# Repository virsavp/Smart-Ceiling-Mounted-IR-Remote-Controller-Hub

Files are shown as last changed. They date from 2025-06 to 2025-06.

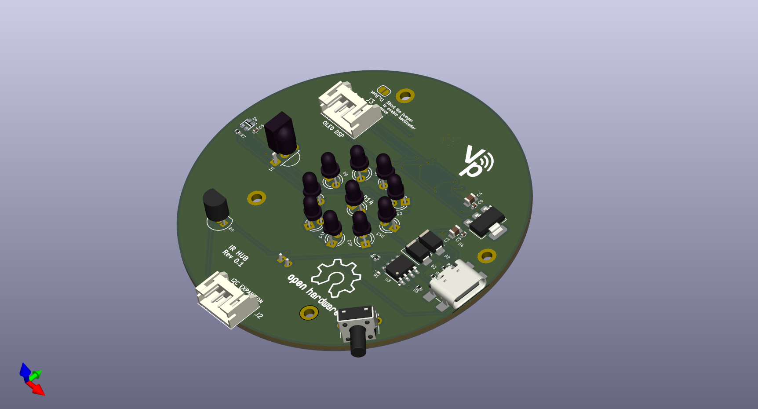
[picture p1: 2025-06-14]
Images/3D ir hub.png

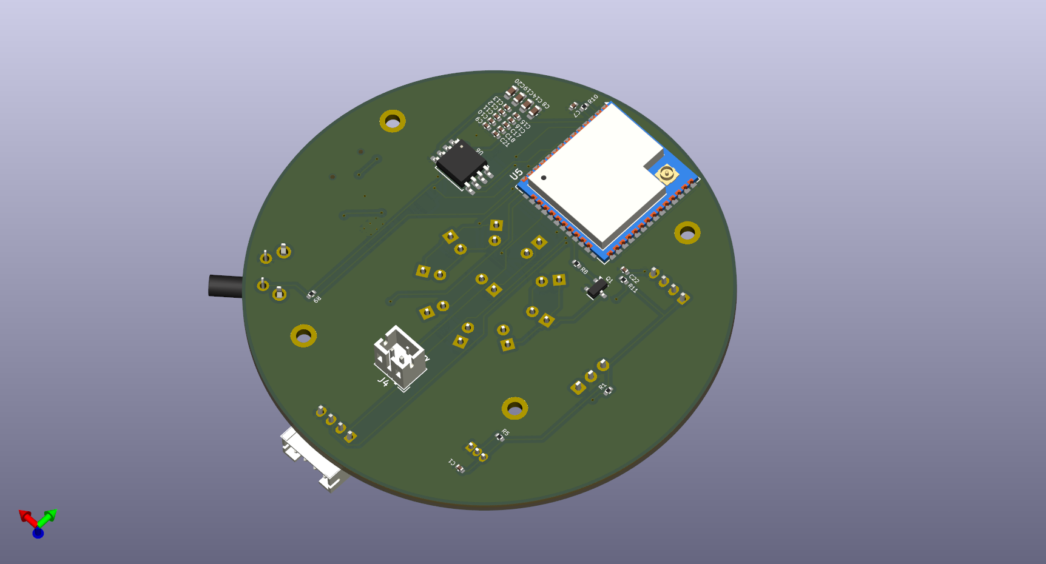
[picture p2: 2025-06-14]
Images/3D ir hub BACK.png

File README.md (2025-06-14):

Universal Remote Controller Hub

📂 Jump to Files:

🔧 Hardware (schematics & PCB)
💻 Firmware Code (coming soon)

This project is a compact, ceiling-mountable, smart IR controller hub based on the ESP32-S3-WROOM. 
It enables universal control of IR-based appliances like TVs, air conditioners, and fans using web UI, OTA, and automation features.

✨ Features

🔁 360° IR transmission with 10× TSAL6200 high-power IR LEDs
🔍 IR learning using TSOP38238 receiver
📡 Wi-Fi OTA updates + USB flashing via BOOT jumper
🌡️ DS18B20 temperature sensor (for fan/AC automation)
🔊 Optional WS2812 RGB LED status indicator
🖥️ Optional OLED display via JST I²C header (GPIO17/18)
🔘 Single config/setup button (GPIO2, safe boot compliant)
💾 External SPI flash (W25Q256JV) for IR code storage
🔌 USB-C power + LiPo battery with TP4056 charge module
🧲 Magnetic ceiling-mount enclosure with transparent IR window and venting

🧱 Hardware Overview	
	
Component	Details
MCU	- ESP32-S3 WROOM
IR TX	- 10× TSAL6200 + 2N2222 transistor driver
IR RX	- TSOP38238
Temp Sensor	- DS18B20 (GPIO10)
OLED Display	- SSD1306 via I²C (GPIO17=SDA, GPIO18=SCL)
RGB LED	- WS2812-2020 (GPIO16)
Button	- Config input on GPIO2 (1k pull-up)
External Flash	- W25Q256JV (CS: GPIO13, CLK: GPIO15, MOSI: GPIO5, MISO: GPIO4)
Power Input	- USB-C + LiPo via TP4056
Regulator	- AMS1117-3.3

📁 Repository Structure

/hardware/         → KiCad schematics, PCB files (licensed under CERN-OHL-S)
/3d_model/         → Enclosure STL or CAD (licensed under CC BY-SA 4.0)
/code/             → ESP32 firmware (to be added after layout)
LICENSE            → Dual license for hardware and enclosure
README.md          → This file

🧾 License

🔧 Schematics & PCB Design: CERN-OHL-S v2

🚧 Development Status

✅ Hardware design complete✅ PCB layout and routing complete🔲 Firmware development starts after placement confirmation

🙌 Contributions

Feel free to fork, improve, or repurpose this design. If you build upon it, keep it open-source under the same licenses.
For issues or suggestions, please open a GitHub issue or contact the maintainer.

Made with ❤️ by Vishnu – Electronics Hobbyist | KiCad Enthusiast | Open Hardware Advocate

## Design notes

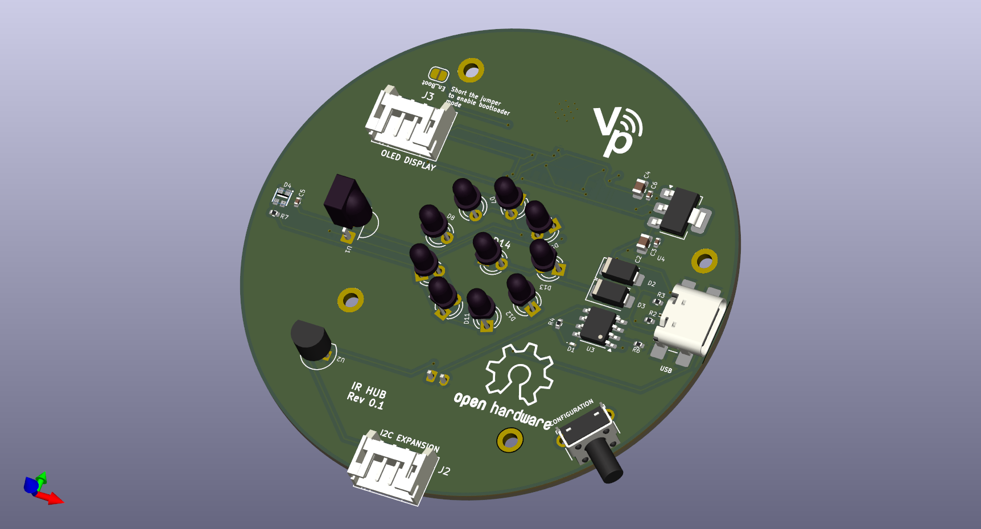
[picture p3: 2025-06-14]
Images/PROJECT.png

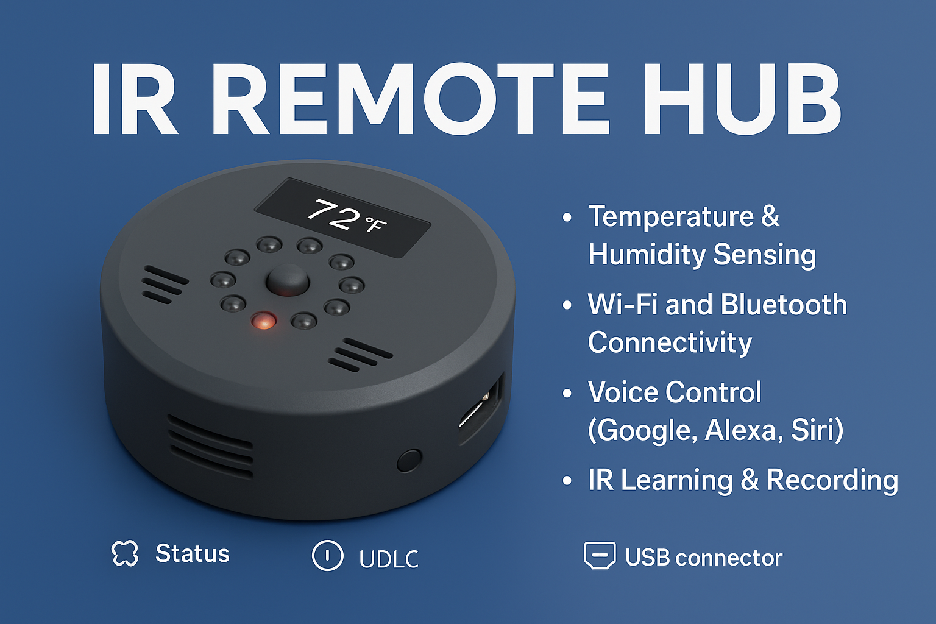
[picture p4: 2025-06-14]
Images/IR Hub.png

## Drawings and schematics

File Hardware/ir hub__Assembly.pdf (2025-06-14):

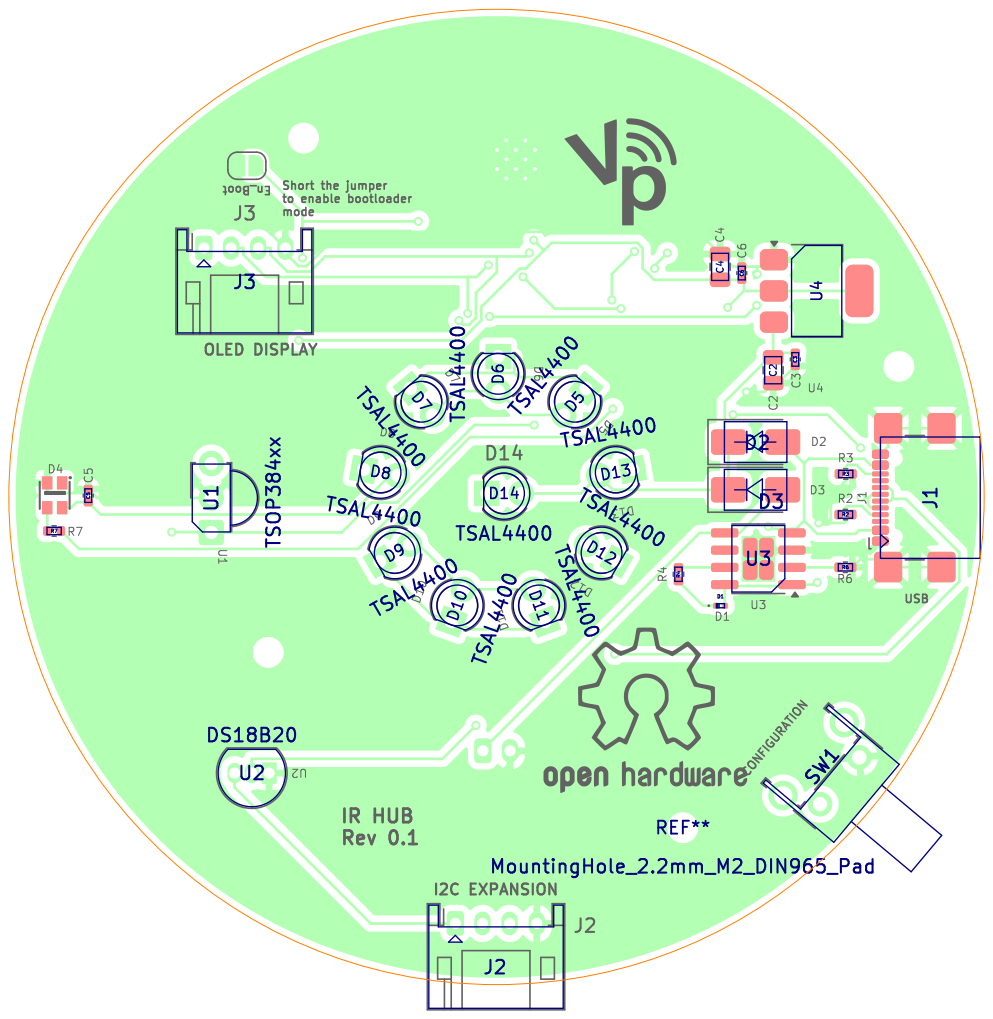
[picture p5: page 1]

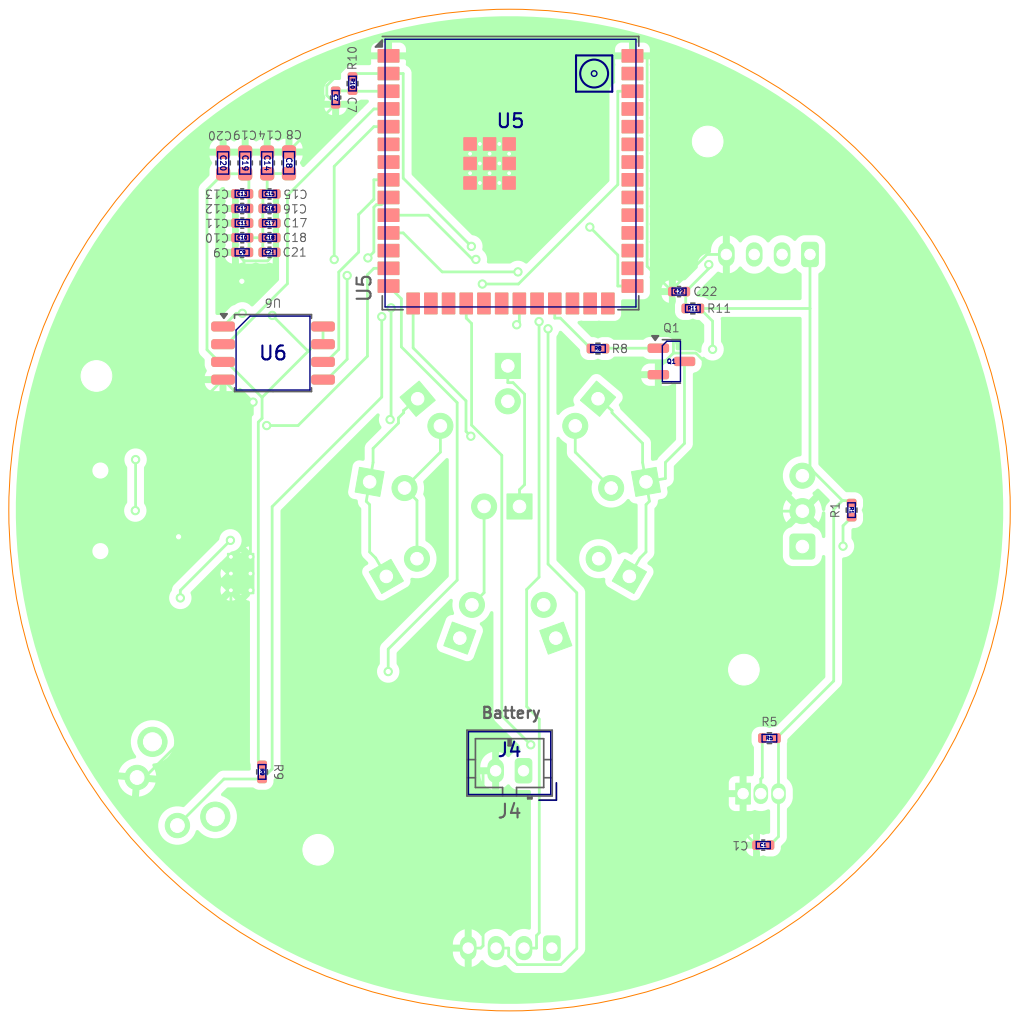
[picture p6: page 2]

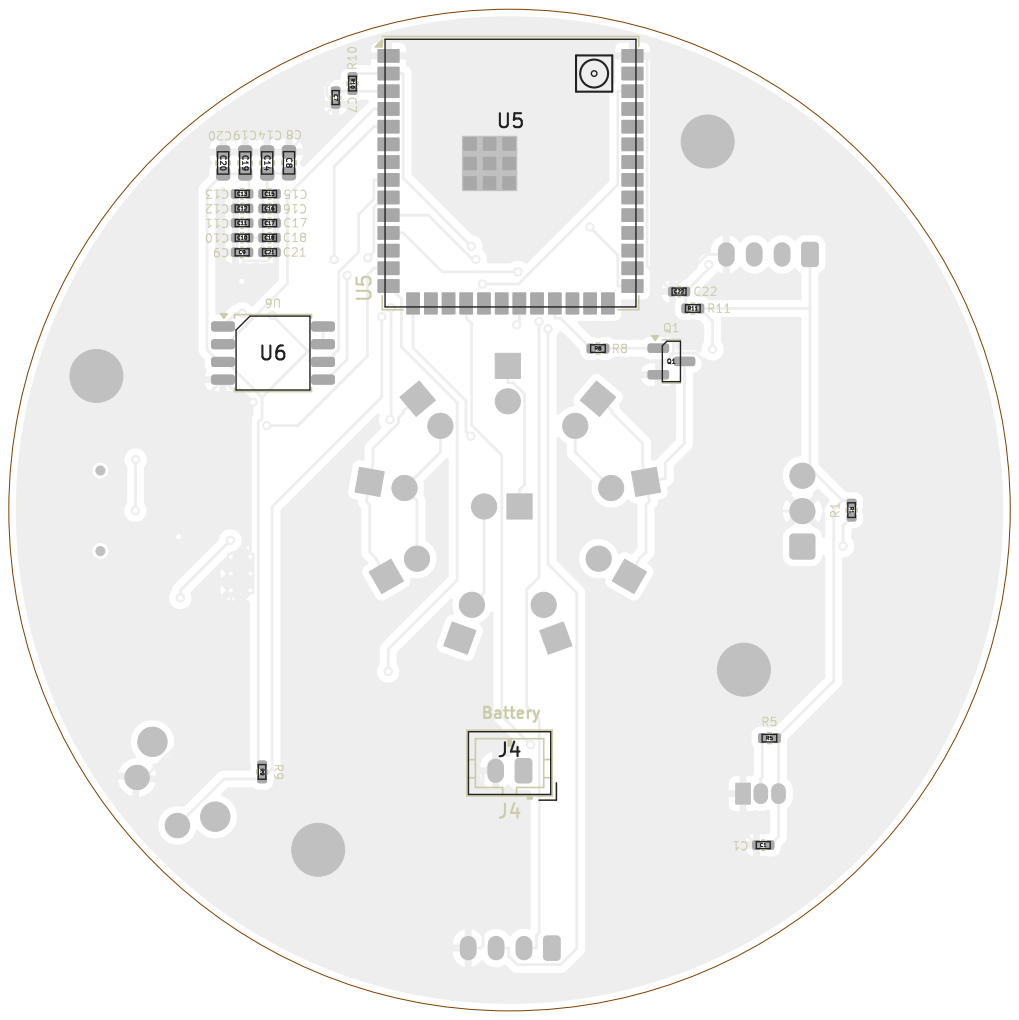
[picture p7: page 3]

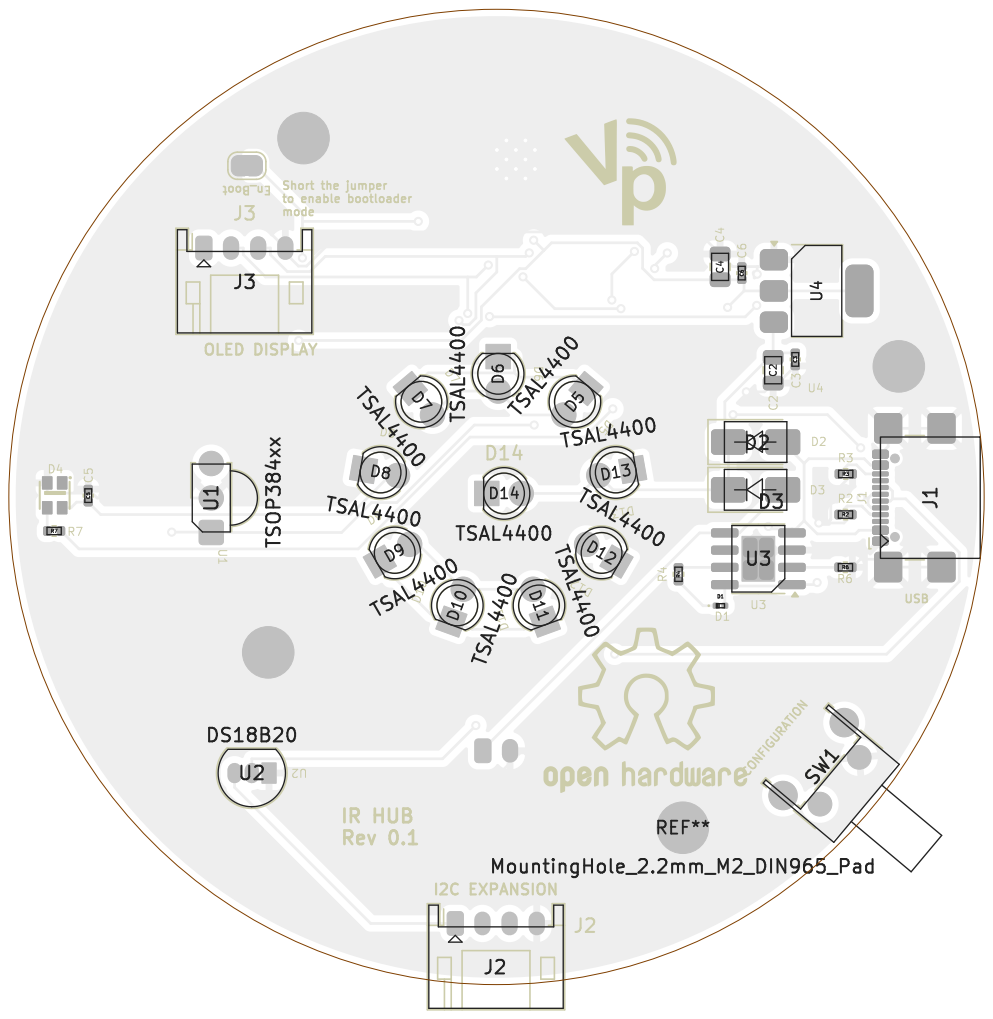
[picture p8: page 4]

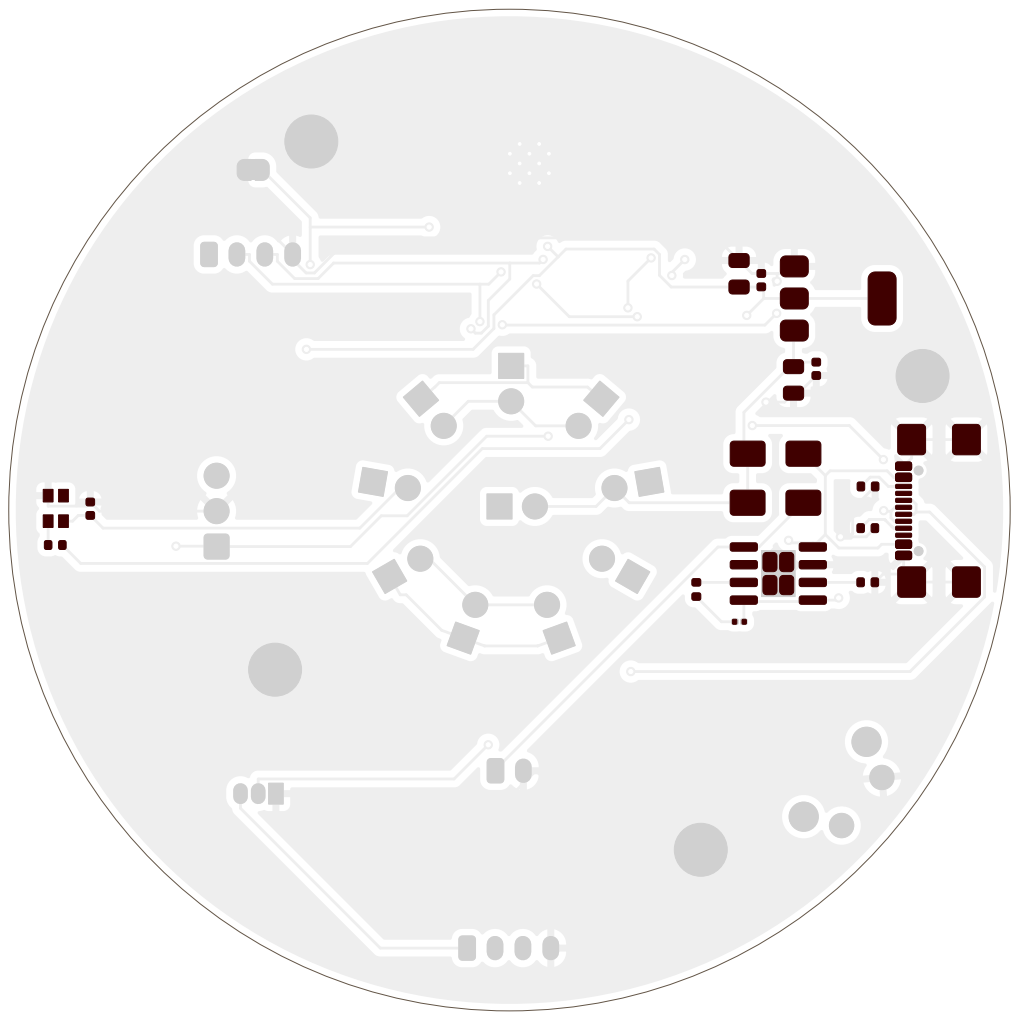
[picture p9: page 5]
D Date: KiCad; E.D.A. 9.0.2 Size: A4; Rev:; Id: /1 Title: File: ir; hub.kicad_pcb Sheet: Light Colors; PCB; Paste; TOP; Board2Pdf:; Light Colors; TOP -; Page 5/6

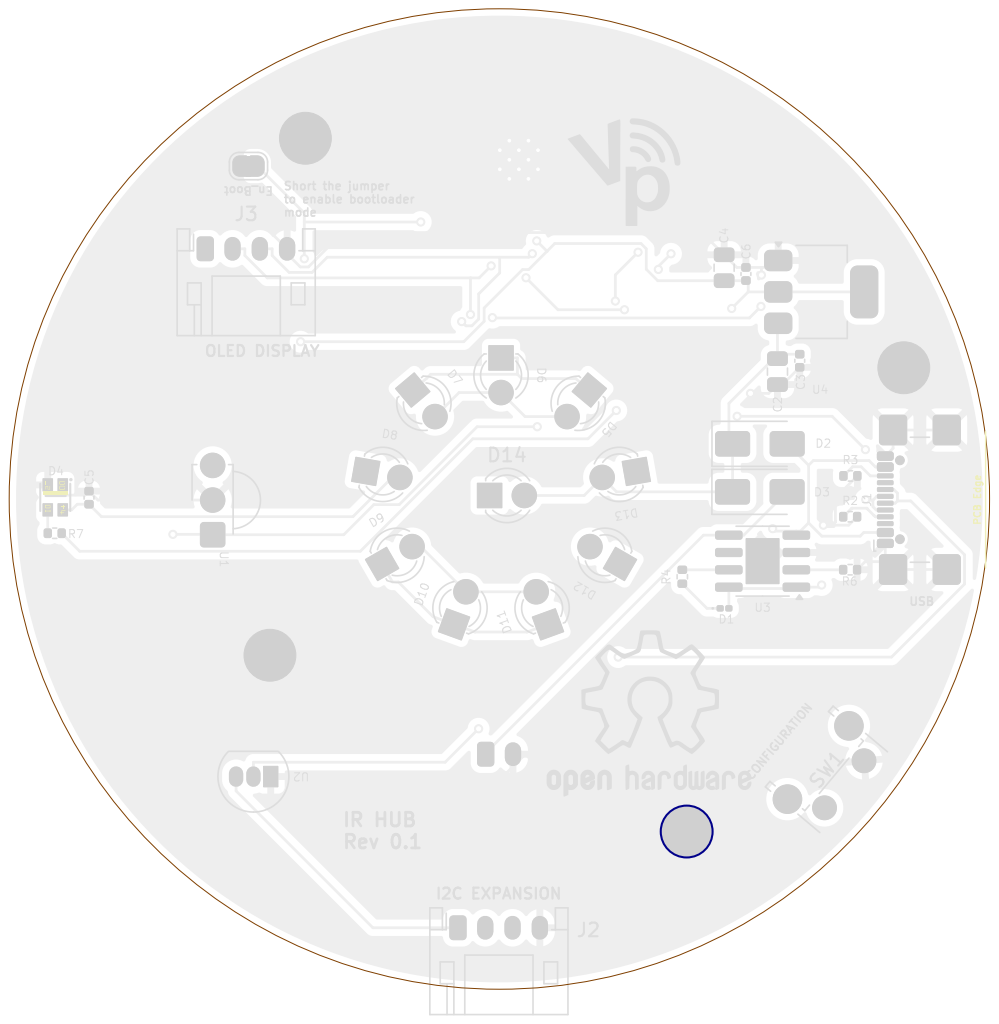
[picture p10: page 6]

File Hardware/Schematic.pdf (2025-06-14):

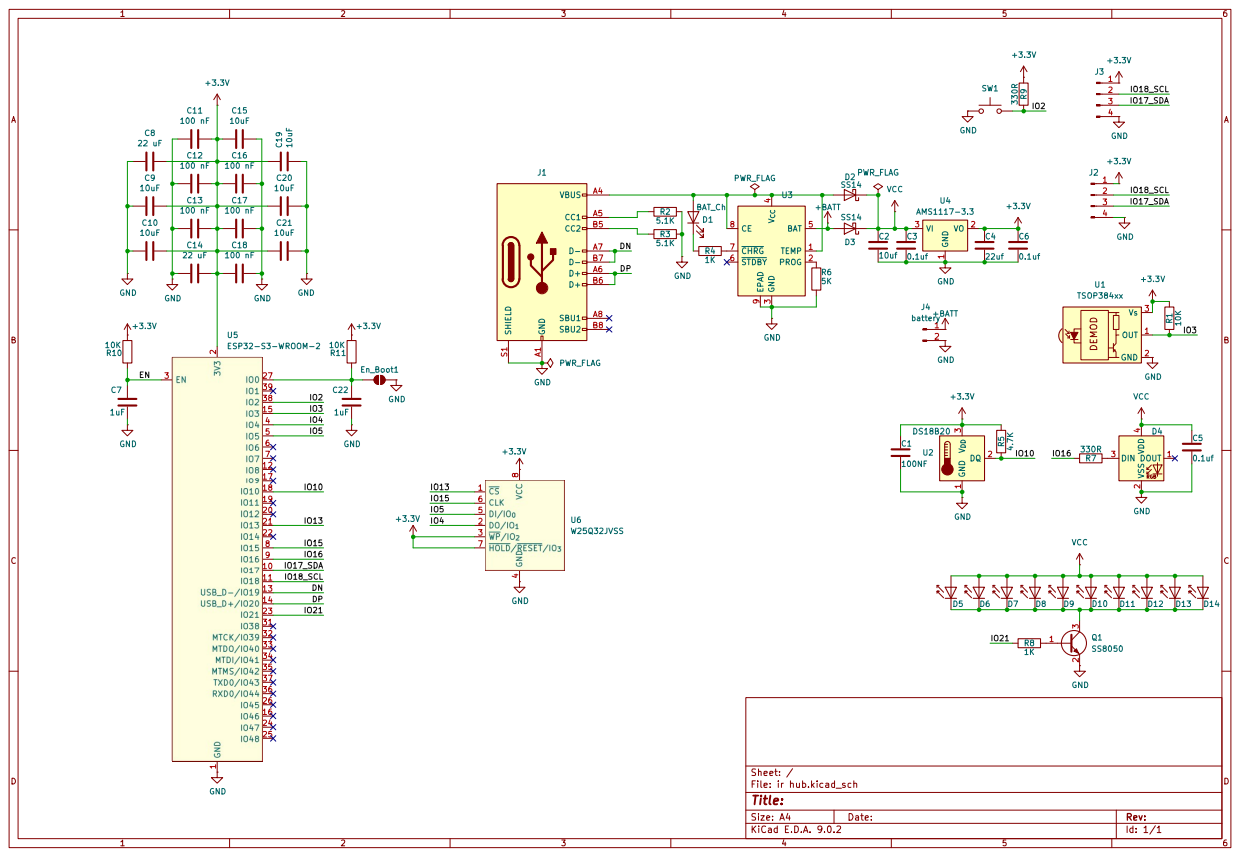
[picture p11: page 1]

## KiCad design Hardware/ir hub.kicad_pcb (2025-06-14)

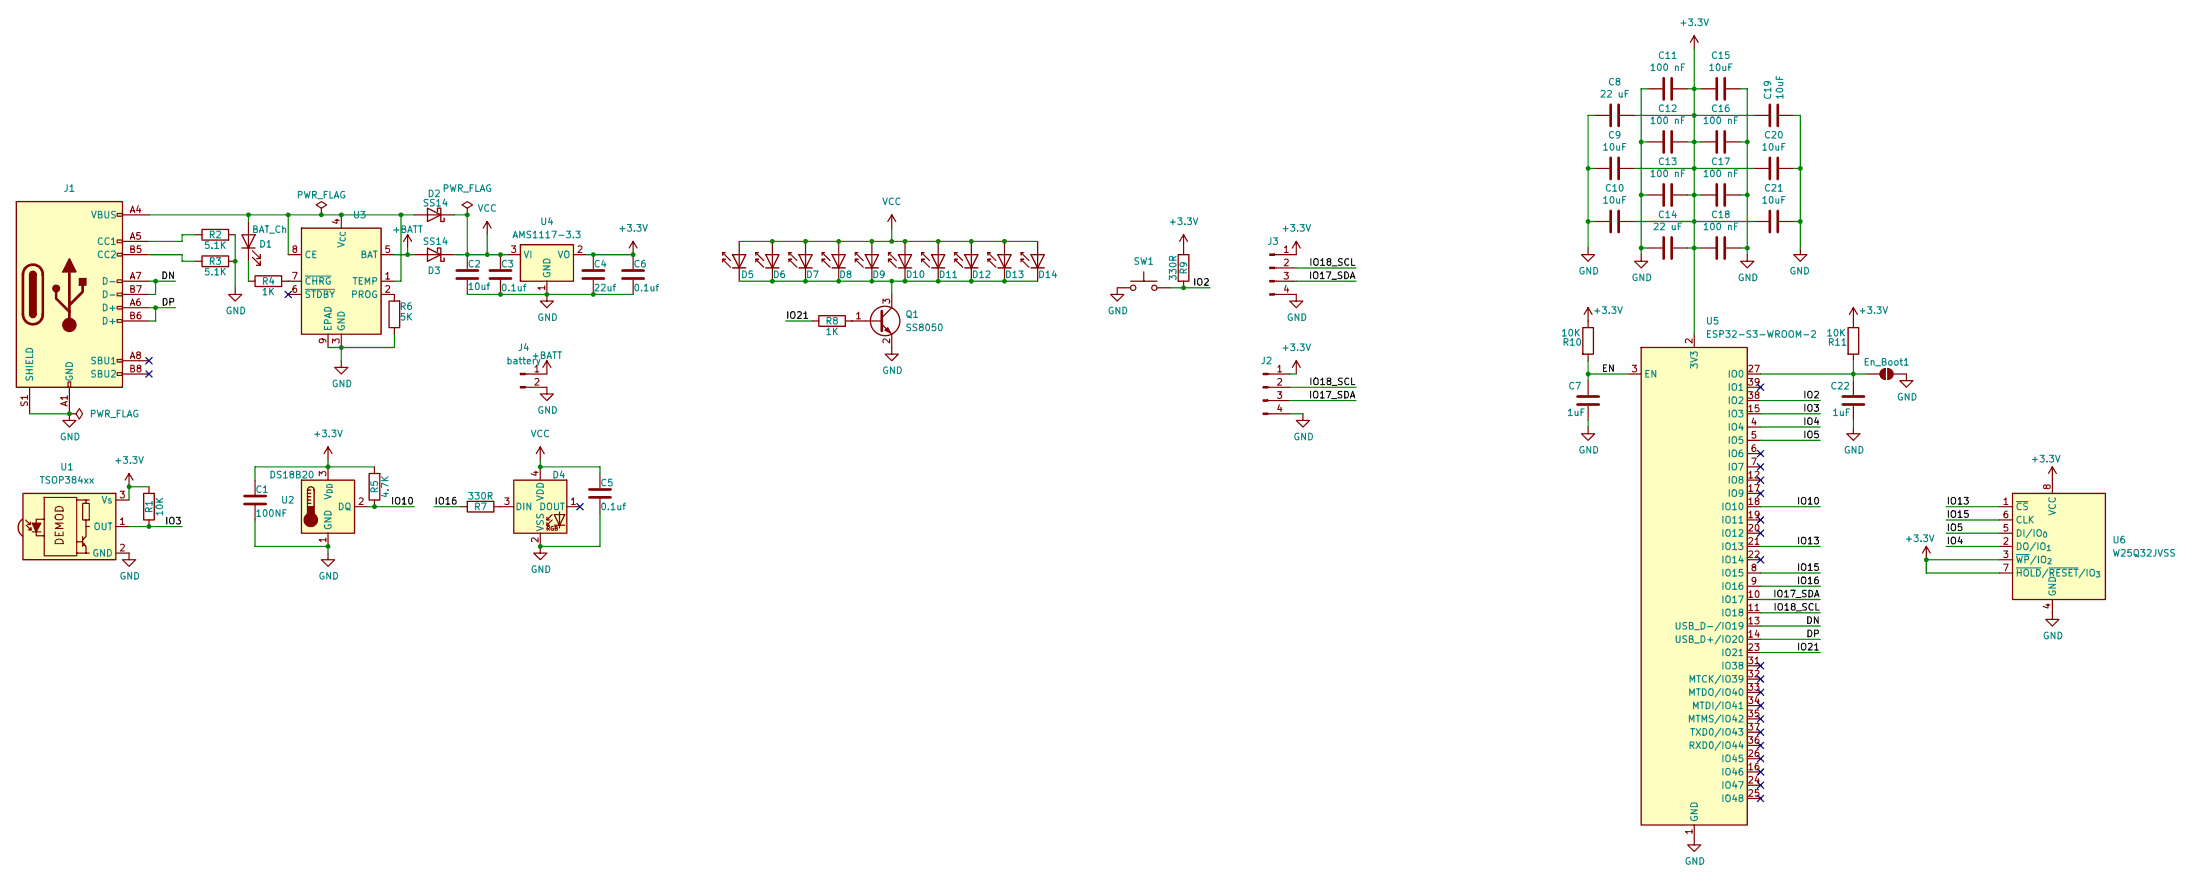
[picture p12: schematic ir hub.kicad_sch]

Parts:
C1: 100NF; C_0402_1005Metric
C2: 10uf; C_0805_2012Metric
C3, C5, C6: 0.1uf; C_0402_1005Metric
C4: 22uf; C_0805_2012Metric
C7, C22: 1uF; C_0402_1005Metric; LCSC C52923
C8, C14: 22 uF; C_0603_1608Metric; LCSC C59461
C9, C10, C15, C21: 10uF; C_0402_1005Metric; LCSC C15525
C11, C12, C13, C16, C17, C18: 100 nF; C_0402_1005Metric; LCSC C1525
C19, C20: 10uF; C_0603_1608Metric; LCSC C19702
D1: BAT_Ch; LED_0201_0603Metric
D2, D3: SS14; D_SMA
D4: WS2812B-2020; LED-SMD_4P-L2.0-W2.0-TL_WS2812B-2020
D5, D6, D7, D8, D9, D10, D11, D12, D13, D14: TSAL4400; LED_D3.0mm_IRBlack
En_Boot1: SolderJumper_2_Open; SolderJumper-2_P1.3mm_Open_RoundedPad1.0x1.5mm
J1: USB_C_Receptacle_USB2.0_16P; USB_C_Receptacle_GCT_USB4110
J2: I2C EXPANSION; JST_PH_S4B-PH-K_1x04_P2.00mm_Horizontal
J3: OLED DSP; JST_PH_S4B-PH-K_1x04_P2.00mm_Horizontal
J4: battery; JST_PH_B2B-PH-K_1x02_P2.00mm_Vertical
Q1: SS8050; SOT-23
R1, R10, R11: 10K; R_0402_1005Metric
R2, R3: 5.1K; R_0402_1005Metric
R4, R8: 1K; R_0402_1005Metric
R5: 4.7K; R_0402_1005Metric
R6: 5K; R_0402_1005Metric
R7, R9: 330R; R_0402_1005Metric
SW1: BTN; SW_Tactile_SPST_Angled_PTS645Vx83-2LFS
U1: TSOP384xx; Vishay_MINICAST-3Pin
U2: DS18B20; TO-92_Inline
U3: TP4056-42-ESOP8; SOIC-8-1EP_3.9x4.9mm_P1.27mm_EP2.41x3.3mm_ThermalVias
U4: AMS1117-3.3; SOT-223-3_TabPin2
U5: ESP32-S3-WROOM-2; ESP32-S3-WROOM-1U
U6: W25Q32JVSS; SOIC-8_5.3x5.3mm_P1.27mm

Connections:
+3.3V: C1.1, C4.1, C6.1, C8.1, C9.1, C10.1, C11.1, C12.1, C13.1, C14.1, C15.2, C16.2, C17.2, C18.2, C19.1, C20.2, C21.2, J2.1, J3.1, R1.2, R5.2, R9.1, R10.1, R11.1, U1.3 (Vs), U2.3 (V_{DD}), U4.2 (VO), U5.2 (3V3), U6.3 (~WP/IO_{2}), U6.7 (~HOLD/~RESET/IO_{3}), U6.8 (VCC)
+BATT: D3.2 (A), J4.1, U3.5 (BAT)
/DN: J1.A7 (D-), J1.B7 (D-), U5.13 (USB_D-/IO19)
/DP: J1.A6 (D+), J1.B6 (D+), U5.14 (USB_D+/IO20)
/EN: C7.1, R10.2, U5.3 (EN)
/IO2: R9.2, SW1.2, U5.38 (IO2)
/IO3: R1.1, U1.1 (OUT), U5.15 (IO3)
/IO4: U5.4 (IO4), U6.2 (DO/IO_{1})
/IO5: U5.5 (IO5), U6.5 (DI/IO_{0})
/IO10: R5.1, U2.2 (DQ), U5.18 (IO10)
/IO13: U5.21 (IO13), U6.1 (~CS)
/IO15: U5.8 (IO15), U6.6 (CLK)
/IO16: R7.2, U5.9 (IO16)
/IO17_SDA: J2.3, J3.3, U5.10 (IO17)
/IO18_SCL: J2.2, J3.2, U5.11 (IO18)
/IO21: R8.1, U5.23 (IO21)
GND: C1.2, C2.2, C3.2, C4.2, C5.2, C6.2, C7.2, C8.2, C9.2, C10.2, C11.2, C12.2, C13.2, C14.2, C15.1, C16.1, C17.1, C18.1, C19.2, C20.1, C21.1, C22.2, D4.2 (VSS), En_Boot1.2 (B), J1.A1 (GND), J1.A12 (GND), J1.B1 (GND), J1.B12 (GND), J1.S1 (SHIELD), J2.4, J3.4, J4.2, Q1.2 (E), R2.2, R3.2, R6.1, SW1.1, U1.2 (GND), U2.1 (GND), U3.3 (GND), U3.9 (EPAD), U4.1 (GND), U5.1 (GND), U5.40 (GND), U5.41 (GND), U6.4 (GND); also elsewhere on the board
unnamed: D1.2 (A), D2.2 (A), J1.A4 (VBUS), J1.A9 (VBUS), J1.B4 (VBUS), J1.B9 (VBUS), U3.1 (TEMP), U3.4 (V_{CC}), U3.8 (CE)
unnamed: D1.1 (K), R4.1
unnamed: D4.3 (DIN), R7.1
unnamed: D5.1 (K), D6.1 (K), D7.1 (K), D8.1 (K), D9.1 (K), D10.1 (K), D11.1 (K), D12.1 (K), D13.1 (K), D14.1 (K), Q1.3 (C)
unnamed 21: C22.1, En_Boot1.1 (A), R11.2, U5.27 (IO0); also elsewhere on the board
unnamed: J1.A5 (CC1), R2.1
unnamed: J1.B5 (CC2), R3.1
unnamed: Q1.1 (B), R8.2
unnamed: R6.2, U3.2 (PROG)
unnamed: R4.2, U3.7 (~CHRG)
VCC: C2.1, C3.1, C5.1, D2.1 (K), D3.1 (K), D4.4 (VDD), D5.2 (A), D6.2 (A), D7.2 (A), D8.2 (A), D9.2 (A), D10.2 (A), D11.2 (A), D12.2 (A), D13.2 (A), D14.2 (A), U4.3 (VI)

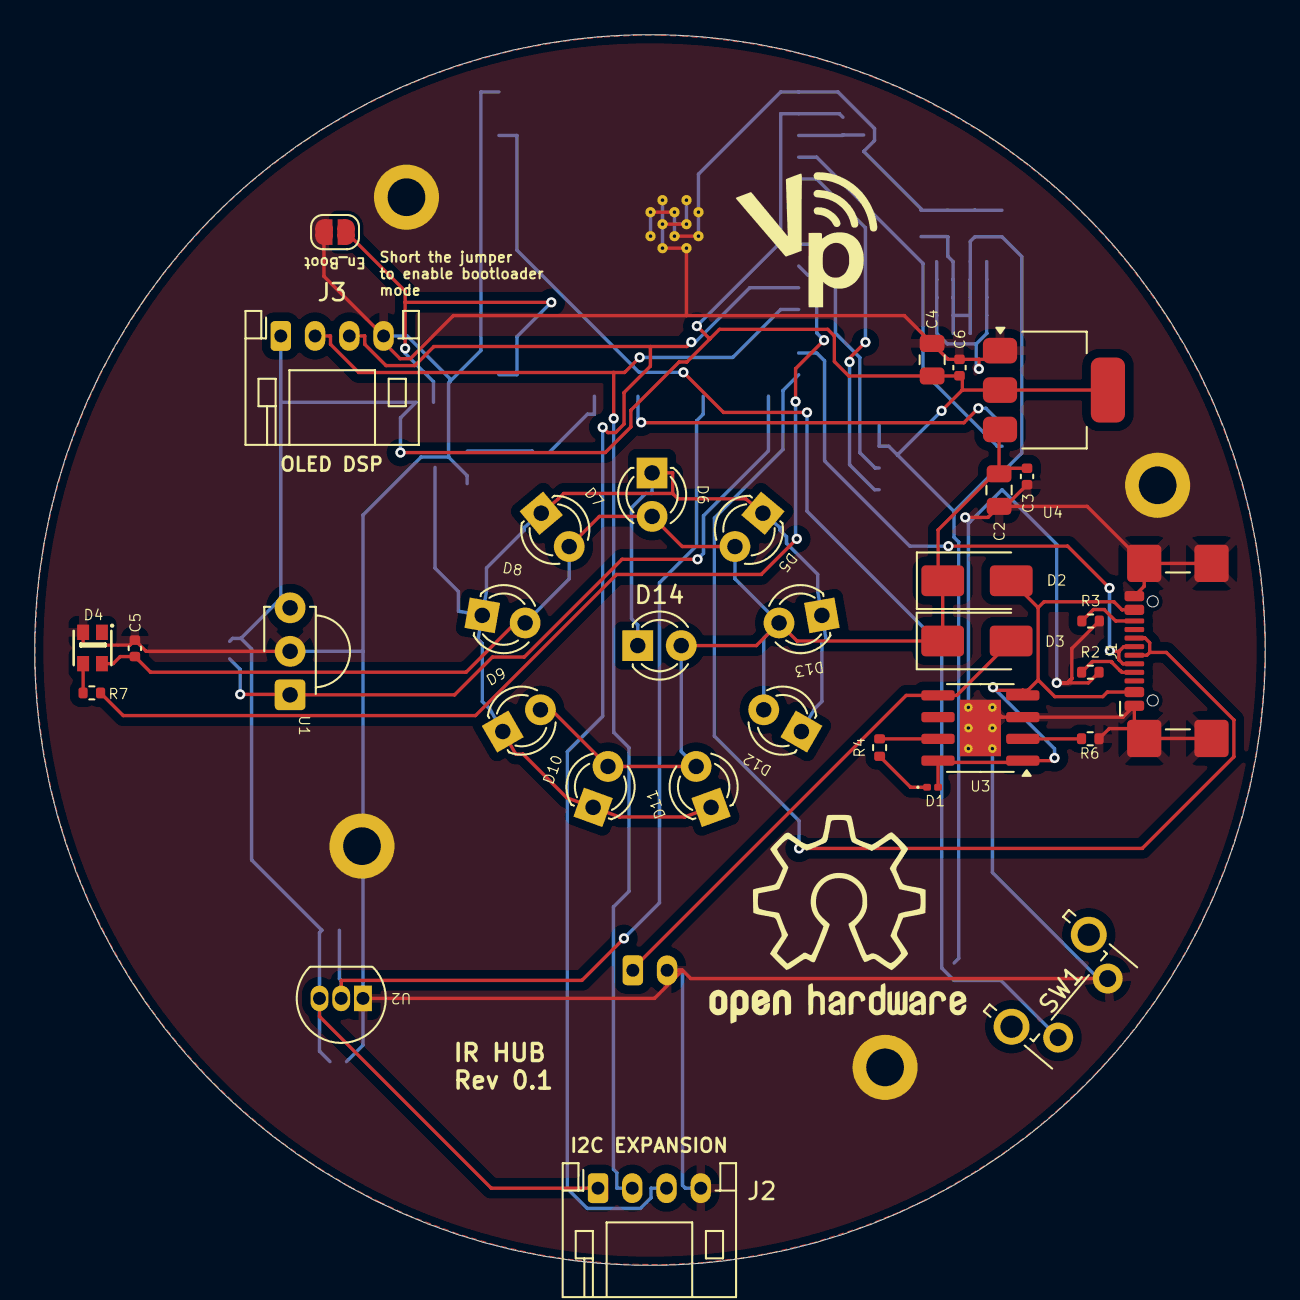
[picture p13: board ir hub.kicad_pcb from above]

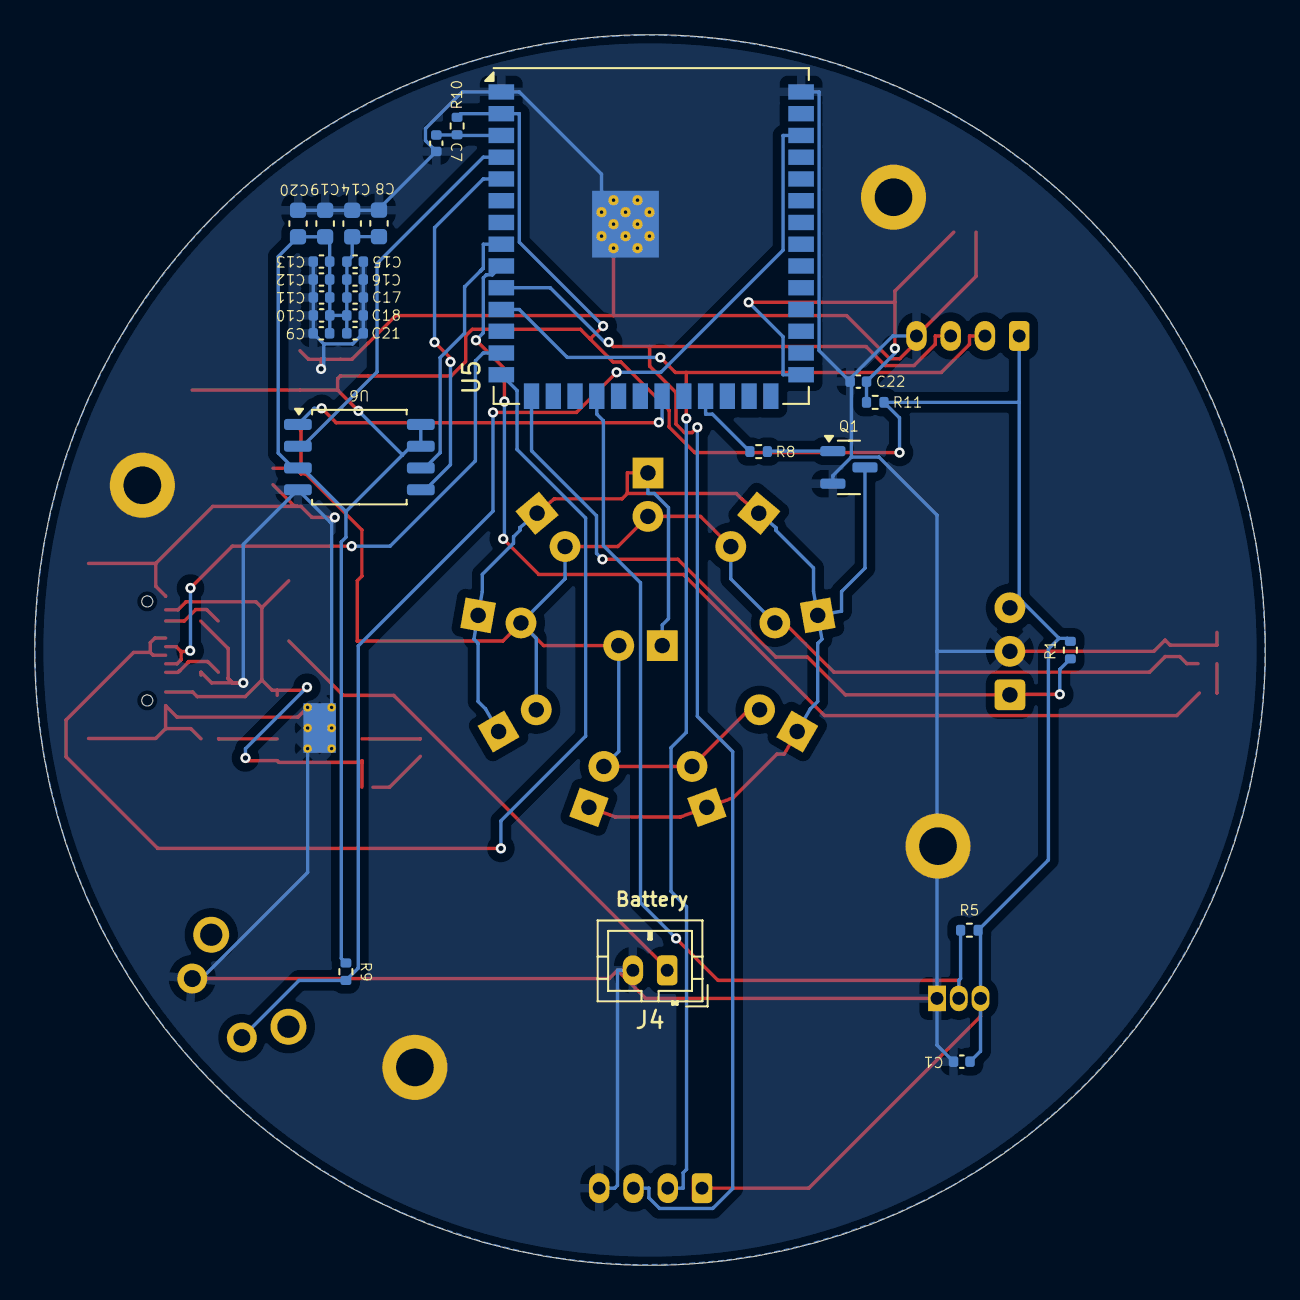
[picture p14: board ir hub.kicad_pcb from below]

Board: 2 copper layers, 71.8 x 71.8 mm, 60 parts (27 on the bottom side), 28 nets.

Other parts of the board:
En_Boot: SolderJumper_2_Open; SolderJumper-2_P1.3mm_Open_RoundedPad1.0x1.5mm

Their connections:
GND: En_Boot.2 (B); also elsewhere on the board
unnamed 21: En_Boot.1 (A); also elsewhere on the board
